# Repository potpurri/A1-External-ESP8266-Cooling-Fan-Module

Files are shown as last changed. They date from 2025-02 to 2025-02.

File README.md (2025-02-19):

# ESP8266-based Fan Control for Bambu Lab A1 3D Printer

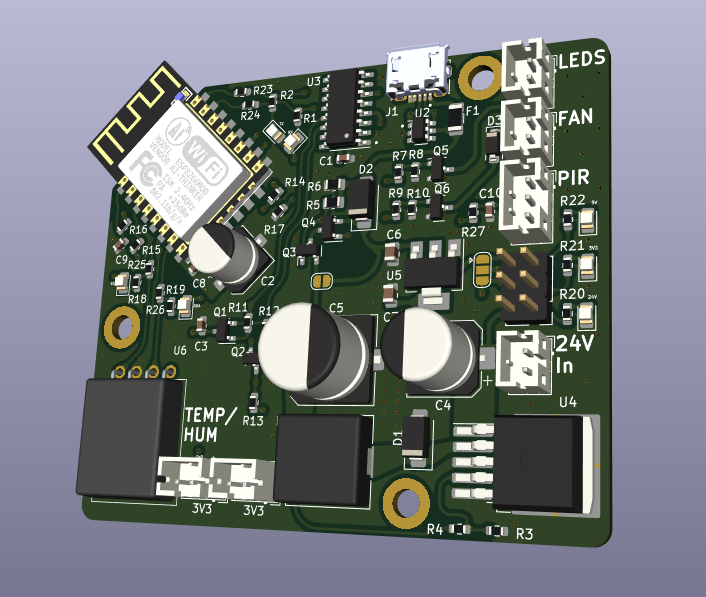
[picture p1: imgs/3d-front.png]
3D Front


## Overview

This project showcases an ESP8266-based board designed to control an external fan to enhance nozzle and print cooling on the Bambu Lab A1 3D printer. The PCB consists of 4 layers in the stack-up: signals, ground, power, and signals.

**Note:** This project is a work in progress.

## Features

The board includes the following components:

- **ESP-12F module**: For wireless communication. The ESP-12F module allows the board to connect to a Wi-Fi network, enabling remote monitoring and control.
- **CH340C**: USB to UART converter for programming the ESP8266. It makes it easy to upload firmware updates or make changes to the program running on the ESP8266.
- **AM2320**: Digital temperature and humidity sensor. It provides accurate readings of the ambient temperature and humidity levels, which can be used to optimize the cooling process.
- **External LED connections**: To drive LEDs located on the printer. These LEDs can provide visual feedback, status indicators, or ambient lighting.
- **External fan connection**: For increased cooling. The fan helps enhance nozzle and print cooling, improving print quality by preventing overheating and warping.
- **PIR sensor connection**: Allows connecting a motion sensor to the board. It can detect motion and be used for various purposes, such as turning on the fan or LEDs when motion is detected near the printer.
- **Buck converter (LM2596)**: Used to step down the voltage from 24V to 5V. This is necessary because the printer's power supply typically provides 24V, but the board components require lower voltage levels to operate safely.
- **AMS1117**: Voltage regulator that further steps down the voltage from 5V to 3.3V, ensuring the ESP-12F module operates properly without being damaged.

## Images

Below are images of the PCB:

3D render of the front view of the PCB

3D Front

3D render of the back view of the PCB

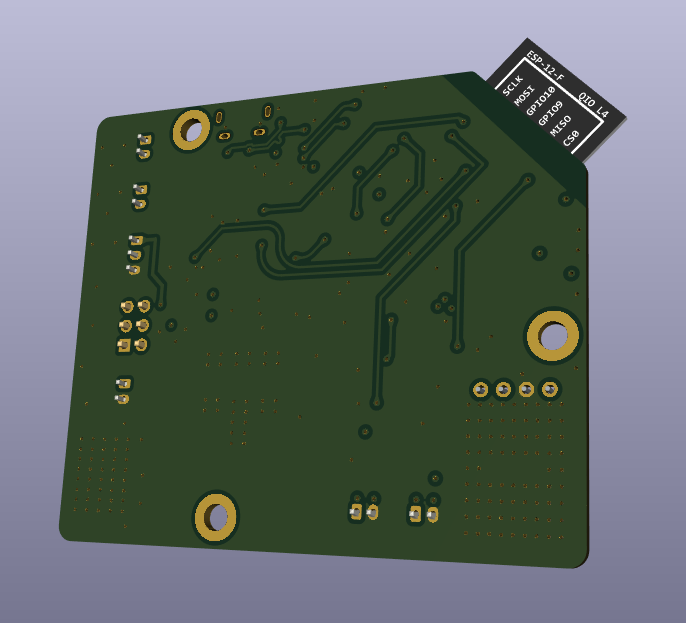
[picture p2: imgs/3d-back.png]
3D Back


Front view of the actual PCB

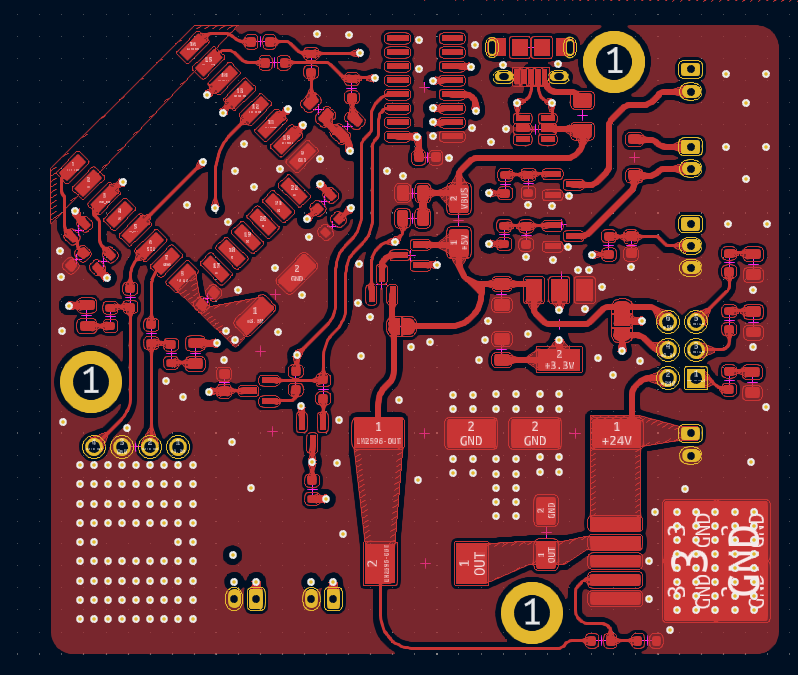
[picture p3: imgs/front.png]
Front


Ground layer of the PCB stack-up

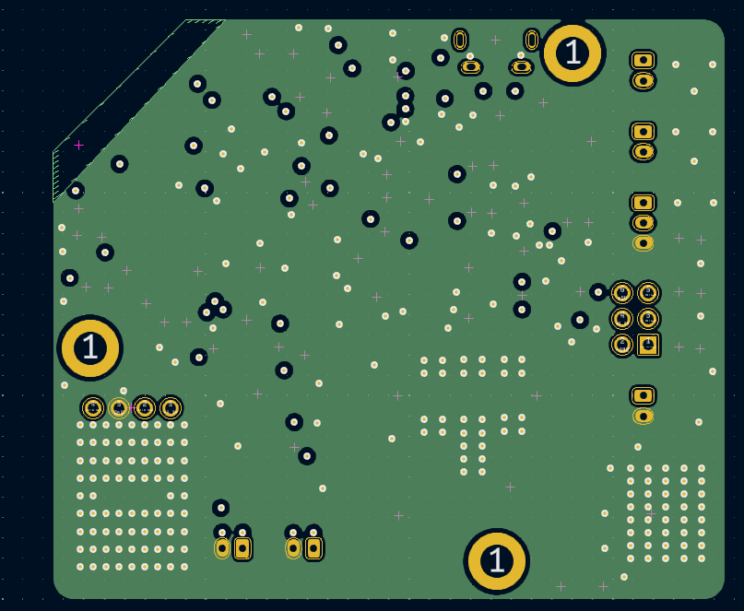
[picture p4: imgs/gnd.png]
Ground


Power layer of the PCB stack-up

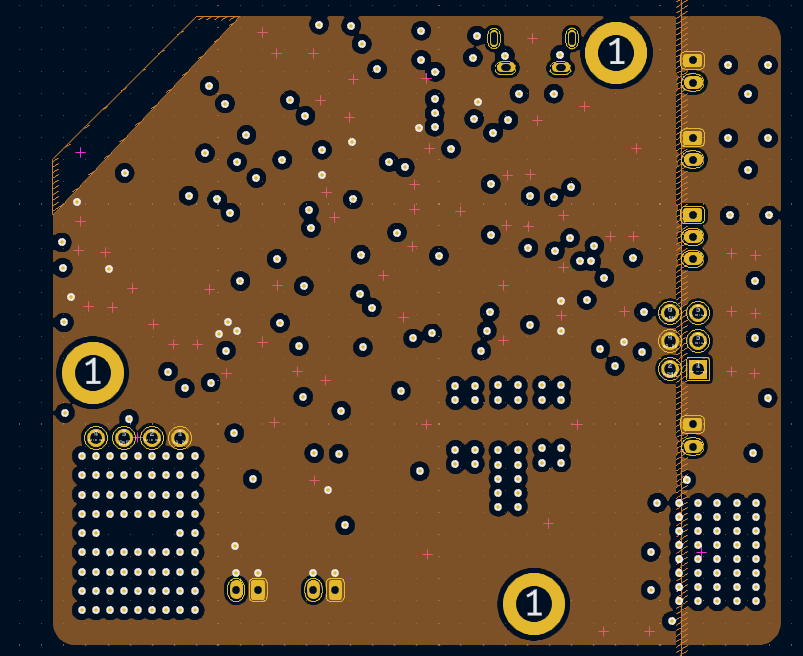
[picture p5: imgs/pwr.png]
Power


Back view of the PCB

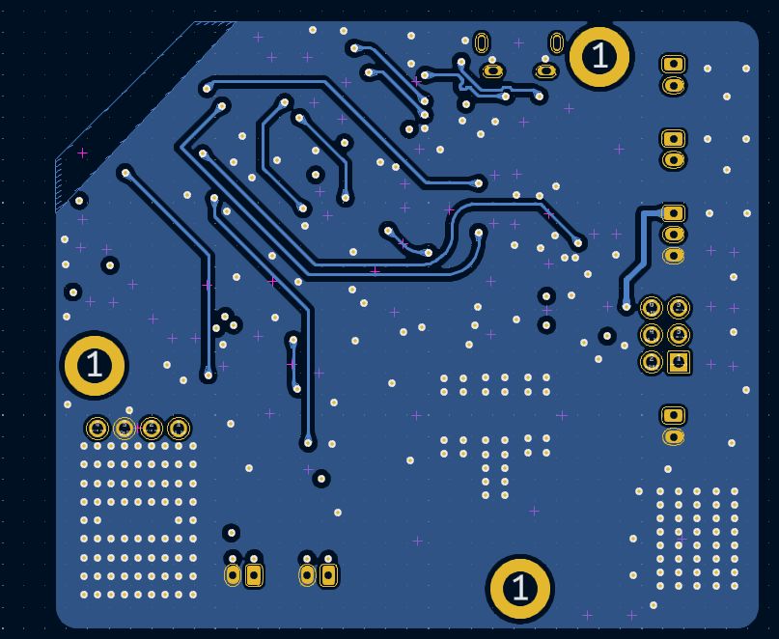
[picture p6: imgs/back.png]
Back


## Schematics

For detailed schematics, please refer to the [schematic PDF](imgs/schematic.pdf).

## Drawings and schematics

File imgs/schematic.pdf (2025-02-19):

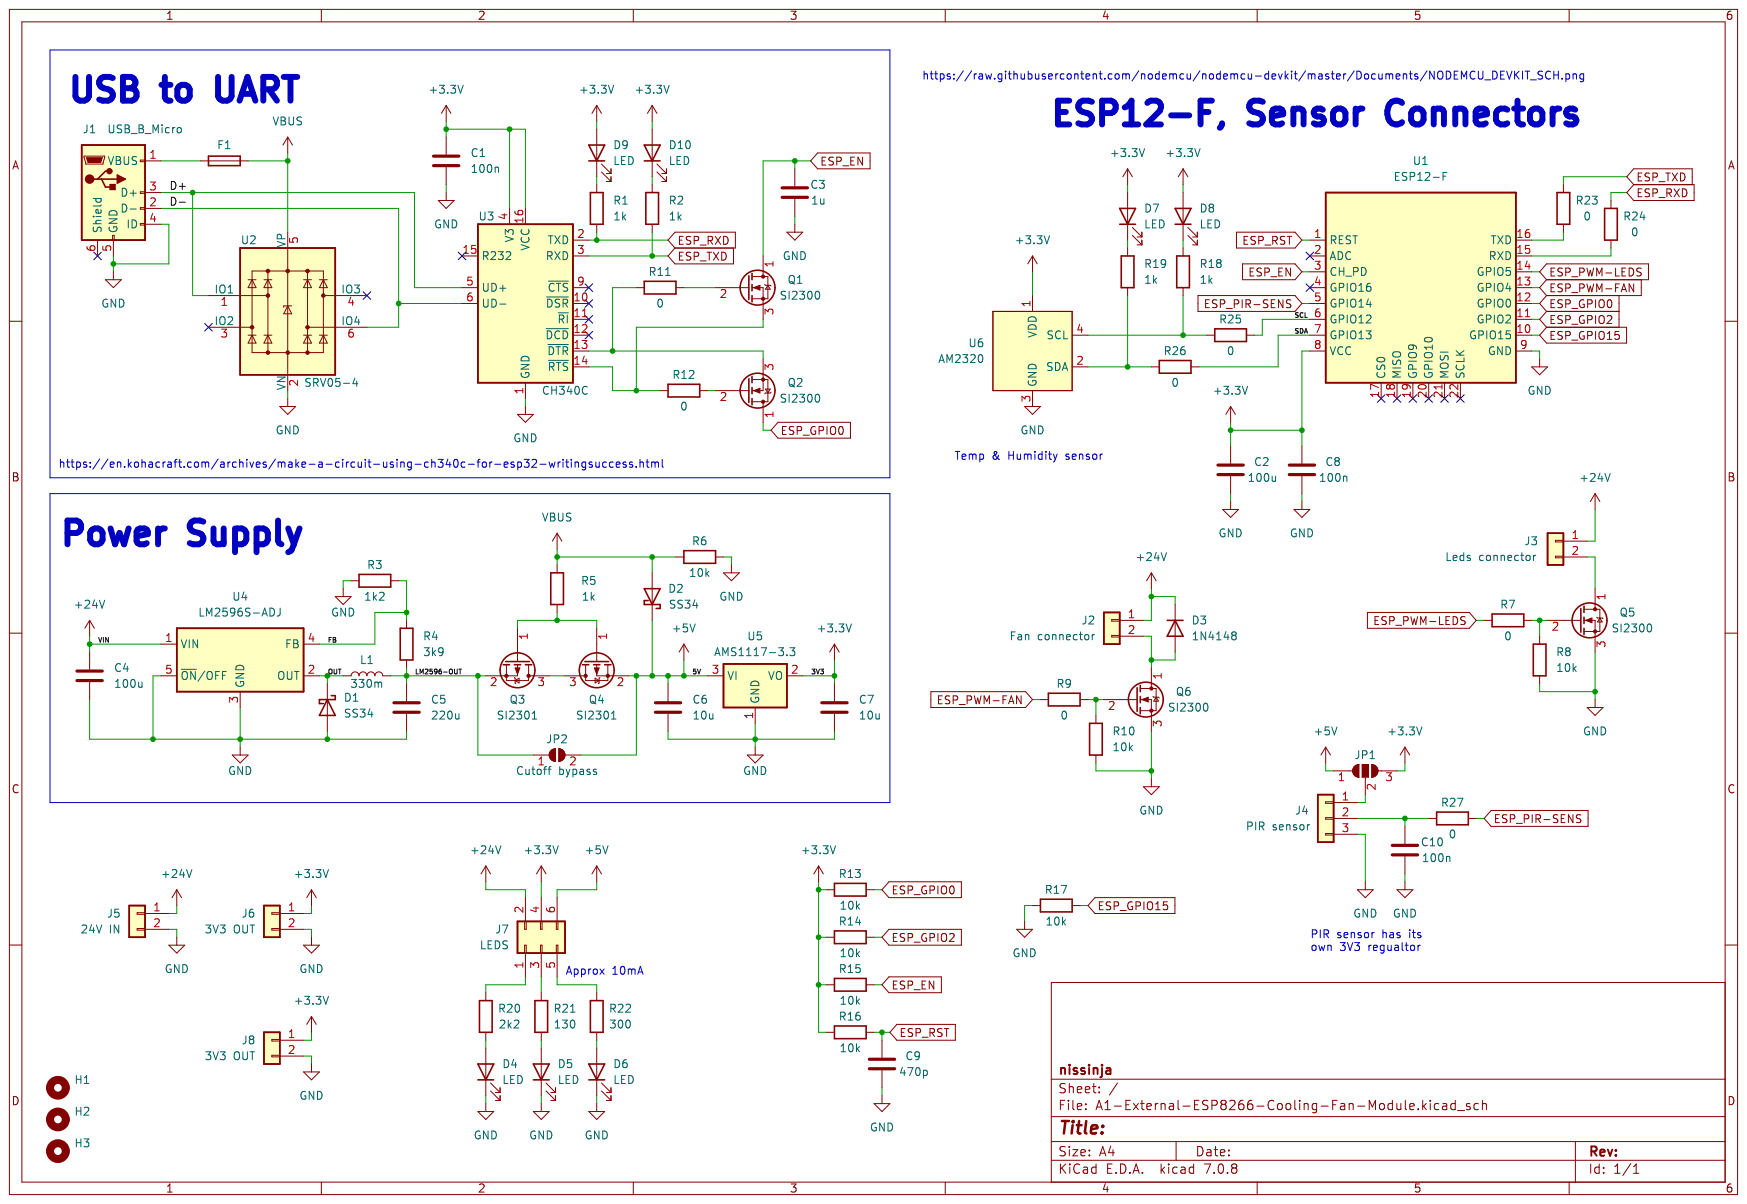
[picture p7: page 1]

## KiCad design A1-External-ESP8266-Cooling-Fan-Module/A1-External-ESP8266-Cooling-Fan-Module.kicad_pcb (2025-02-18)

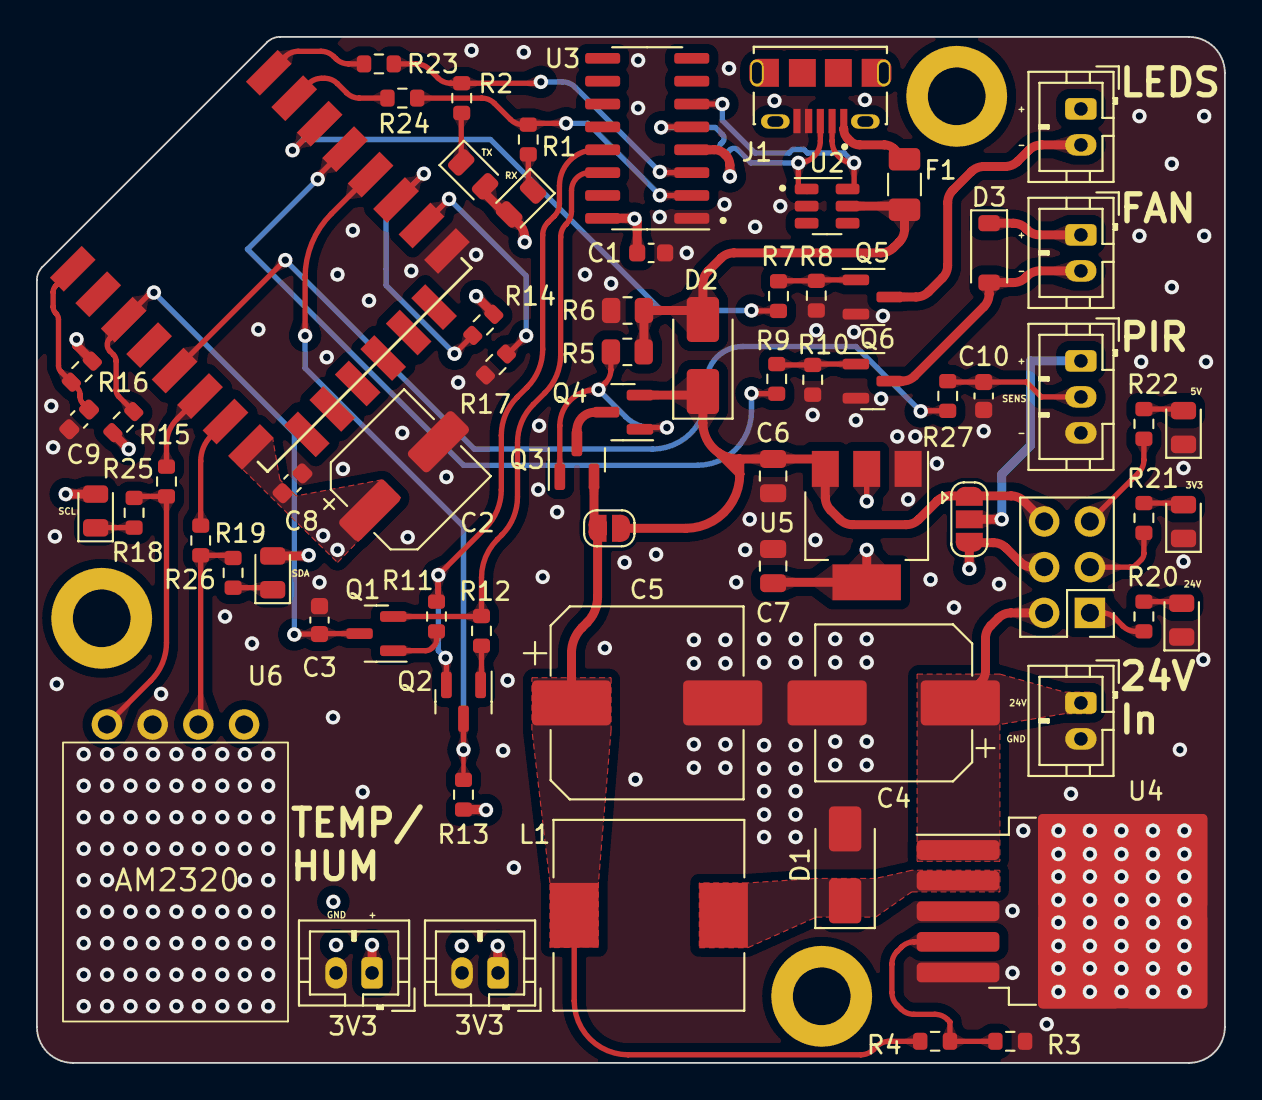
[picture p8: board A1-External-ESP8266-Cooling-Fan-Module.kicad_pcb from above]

Board: 4 copper layers, 66.0 x 57.0 mm, 74 parts (0 on the bottom side), 49 nets.

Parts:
C1, C8, C10: 100n; C_0603_1608Metric
C2: 100u; CP_Elec_6.3x7.7
C3: 1u; C_0603_1608Metric
C4: 100u; CP_Elec_8x10.5
C5: 220u; CP_Elec_10x10.5
C6, C7: 10u; C_0805_2012Metric
C9: 470p; C_0603_1608Metric
D1, D2: SS34; D_SMA
D3: 1N4148; D_SOD-123
D4, D5, D6, D7, D8, D9, D10: LED; LED_0805_2012Metric
F1: 1A5; Fuse_1206_3216Metric
H1, H2, H3: MountingHole; MountingHole_3.2mm_M3_DIN965_Pad
J1: USB_B_Micro; AMPHENOL_10118194-0001LF
J2: Fan connector; JST_PH_B2B-PH-K_1x02_P2.00mm_Vertical
J3: Leds connector; JST_PH_B2B-PH-K_1x02_P2.00mm_Vertical
J4: PIR sensor; JST_PH_B3B-PH-K_1x03_P2.00mm_Vertical
J5: 24V IN; JST_PH_B2B-PH-K_1x02_P2.00mm_Vertical
J6, J8: 3V3 OUT; JST_PH_B2B-PH-K_1x02_P2.00mm_Vertical
J7: LEDS; PinHeader_2x03_P2.54mm_Vertical
JP1: SolderJumper_3_Open; SolderJumper-3_P1.3mm_Open_RoundedPad1.0x1.5mm
JP2: Cutoff bypass; SolderJumper-2_P1.3mm_Open_RoundedPad1.0x1.5mm
L1: 330m; L_10.4x10.4_H4.8
Q1, Q2, Q5, Q6: SI2300; SI2300 SOT-23
Q3, Q4: SI2301; SOT-23
R1, R2, R18, R19: 1k; R_0603_1608Metric
R3: 1k2; R_0603_1608Metric
R4: 3k9; R_0603_1608Metric
R5: 1k; R_0805_2012Metric
R6: 10k; R_0805_2012Metric
R7, R9, R11, R12, R23, R24, R25, R26, R27: 0; R_0603_1608Metric
R8, R10, R13, R14, R15, R16, R17: 10k; R_0603_1608Metric
R20: 2k2; R_0603_1608Metric
R21: 130; R_0603_1608Metric
R22: 300; R_0603_1608Metric
U1: ESP12-F; ESP-12E_SMD
U2: SRV05-4; SOT-23-6
U3: CH340C; SOIC-16_3.9x9.9mm_P1.27mm
U4: LM2596S-ADJ; TO-263-5_TabPin3
U5: AMS1117-3.3; SOT-223-3_TabPin2
U6: AM2320

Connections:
+3.3V: C1.1, C2.1, C7.1, C8.1, D7.2 (A), D8.2 (A), D9.2 (A), D10.2 (A), J6.1, J7.4, J8.1, JP1.3 (B), R13.2, R14.2, R15.2, R16.2, U1.8 (VCC), U3.4 (V3), U3.16 (VCC), U5.2 (VO), U6.1 (VDD)
+5V: C6.1, D2.1 (K), J7.6, JP1.1 (A), JP2.2 (B), Q4.2 (S), U5.3 (VI)
+24V: C4.1, D3.1 (K), J2.1, J3.1, J5.1, J7.2, U4.1 (VIN)
/D+: J1.3 (D+), U2.1 (IO1), U3.5 (UD+)
/D-: J1.2 (D-), U2.6 (IO4), U3.6 (UD-)
/FB: R3.2, R4.1, U4.4 (FB)
/LM2596-OUT: C5.1, JP2.1 (A), L1.2, Q3.2 (S), R4.2
/OUT: D1.1 (K), L1.1, U4.2 (OUT)
/SCL: R25.1, U1.6 (GPIO12)
/SDA: R26.1, U1.7 (GPIO13)
ESP_EN: C3.1, Q1.1 (D), R15.1, U1.3 (CH_PD)
ESP_GPIO0: Q2.1 (D), R13.1, U1.12 (GPIO0)
ESP_GPIO2: R14.1, U1.11 (GPIO2)
ESP_GPIO15: R17.1, U1.10 (GPIO15)
ESP_PIR-SENS: R27.2, U1.5 (GPIO14)
ESP_PWM-FAN: R9.2, U1.13 (GPIO4)
ESP_PWM-LEDS: R7.2, U1.14 (GPIO5)
ESP_RST: C9.1, R16.1, U1.1 (REST)
ESP_RXD: R1.2, R24.1, U3.2 (TXD)
ESP_TXD: R2.2, R23.1, U3.3 (RXD)
GND: C1.2, C2.2, C3.2, C4.2, C5.2, C6.2, C7.2, C8.2, C9.2, C10.2, D1.2 (A), D4.1 (K), D5.1 (K), D6.1 (K), J1.4 (ID), J1.5 (GND), J4.3, J5.2, J6.2, J8.2, Q5.3 (S), Q6.3 (S), R3.1, R6.2, R8.2, R10.2, R17.2, U1.9 (GND), U2.2 (VN), U3.1 (GND), U4.3 (GND), U4.5 (~ON/OFF), U5.1 (GND), U6.3 (GND)
unnamed: D3.2 (A), J2.2, Q6.1 (D)
unnamed: D4.2 (A), R20.2
unnamed: D5.2 (A), R21.2
unnamed: D6.2 (A), R22.2
unnamed: D7.1 (K), R19.1
unnamed: D8.1 (K), R18.1
unnamed: D9.1 (K), R1.1
unnamed: D10.1 (K), R2.1
unnamed: F1.1, J1.1 (VBUS)
unnamed: J3.2, Q5.1 (D)
unnamed: J4.1, JP1.2 (C)
unnamed: C10.1, J4.2, R27.1
unnamed: J7.1, R20.1
unnamed: J7.3, R21.1
unnamed: J7.5, R22.1
unnamed: Q1.2 (G), R11.2
unnamed: Q1.3 (S), R12.1, U3.14 (~RTS)
unnamed: Q2.2 (G), R12.2
unnamed: Q2.3 (S), R11.1, U3.13 (~DTR)
unnamed: Q3.3 (D), Q4.3 (D)
unnamed: Q3.1 (G), Q4.1 (G), R5.1
unnamed: Q5.2 (G), R7.1, R8.1
unnamed: Q6.2 (G), R9.1, R10.1
unnamed: R24.2, U1.15 (RXD)
unnamed: R23.2, U1.16 (TXD)
unnamed: R18.2, R25.2, U6.4 (SCL)
unnamed: R19.2, R26.2, U6.2 (SDA)
VBUS: D2.2 (A), F1.2, R5.2, R6.1, U2.5 (VP)

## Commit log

2025-01-12 USB to UART, Power Supply Circuit
    [A1-External-ESP8266-Cooling-Fan-Module.kicad_sch]
2025-01-14 fixed 3.3v to ch340 chip
    [A1-External-ESP8266-Cooling-Fan-Module.kicad_sch]
2025-01-19 finished schematic?
    [A1-External-ESP8266-Cooling-Fan-Module.kicad_pcb, A1-External-ESP8266-Cooling-Fan-Module.kicad_sch]
2025-02-18 final layout
    [A1-External-ESP8266-Cooling-Fan-Module.kicad_pcb, A1-External-ESP8266-Cooling-Fan-Module.kicad_sch]
